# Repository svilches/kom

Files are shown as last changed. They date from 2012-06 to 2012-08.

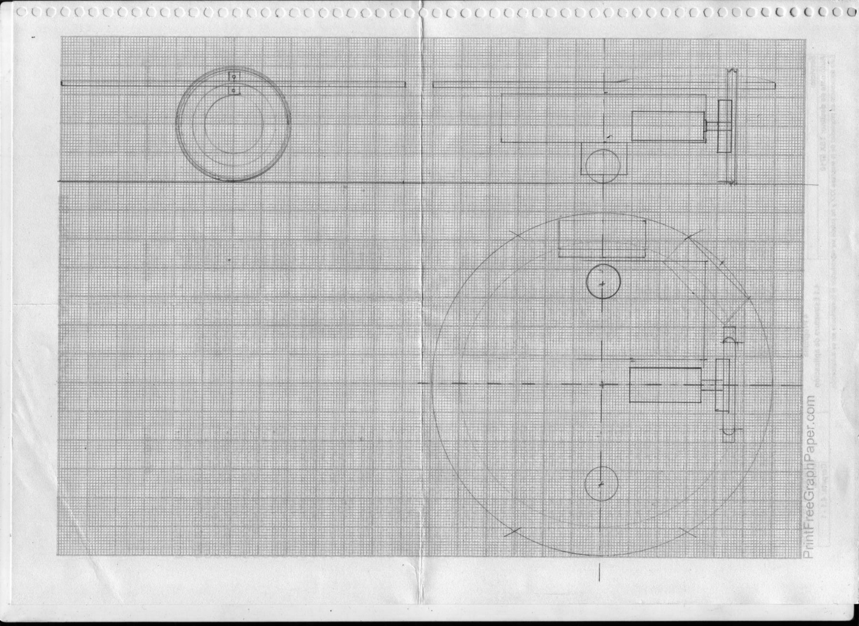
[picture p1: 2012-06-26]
hw/doc/mechs/chassisReqs.jpg

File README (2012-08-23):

CONTENT
kom project source files for both hardware and software
Will include all the source files and documentation for both hardware and software.

GIT RESOURCES
 - Starting point:
	http://www.gitguys.com/topics/skip-the-intro/
 - GIT Book:
	http://git-scm.com/book/ch1-3.html
 - gitg, a graphical tool to see what you are doing to the repository
	sudo apt-get install gitg

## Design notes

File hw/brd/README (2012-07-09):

I'm using the latest kicad (testing) from Adam Wolf's ppa. To use it in Ubuntu:
sudo add-apt-repository ppa:adamwolf/kicad-testing-daily

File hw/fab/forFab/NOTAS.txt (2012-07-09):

Proyecto KOM - Robot KOMbot
== Sergio Vilches ==
- PCB circular, diámetro 130mm
- Hay 2 rendijas en el interior de la PCB a mecanizar. Las ruedas del robot atraviesan la PCB!!! Aparecen en el archivo kom-PCB_Edges.gbr

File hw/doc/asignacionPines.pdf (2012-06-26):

# Asignación de Pines

Arduino Pin | AVR pin | Notas | Uso
0 | PD0 | RX | Conectado al TX del FTDI, Bluetooth o XBee
1 | PD1 | TX | Conectado al RX del FTDI, Bluetooth o XBee
2 | PD2 | INT0 | PUSH, SERVO
3 | PD3 | INT1, PWM | SpeedL
4 | PD4 | | DIR_L
5 | PD5 | PWM*¹ | PWROUT, IRLEDs
6 | PD6 | PWM*² | PWROUT, SERVO
7 | PD7 | | DIR_R
8 | PB0 | | A
9 | PB1 | PWM³ | B
10 | PB2 | PWM⁴ | C
11 | PB3 | PWM,MOSI | SpeedR
12 | PB4 | MISO | D
13 | PB5 | SCK | ServoScanner
A0 | PC0 | | MUX

1
The PWM outputs generated on pins 5 and 6 will have higher-than-expected duty cycles. This is because of interactions with the millis() and delay() functions, which share the same internal timer used to generate those PWM outputs. This will be noticed mostly on low duty-cycle settings (e.g 0 - 10) and may result in a value of 0 not fully turning off the output on pins 5 and 6.
2
(Same)

3
Disabled by Servo.h

4
Disabled by Servo.h

A1 | PC1 | | SERVO, R
A2 | PC2 | | SERVO, G
A3 | PC3 | | SERVO, B
A4 | PC4 | I2C_SDA
A5 | PC5 | I2C_SCL
MUX Pin | Uso

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
8 | encLA
9 | encLB
10 | encRA
11 | encRB
12 | US0
13 | US1
14 | IR0
15 | 0.4*Vin

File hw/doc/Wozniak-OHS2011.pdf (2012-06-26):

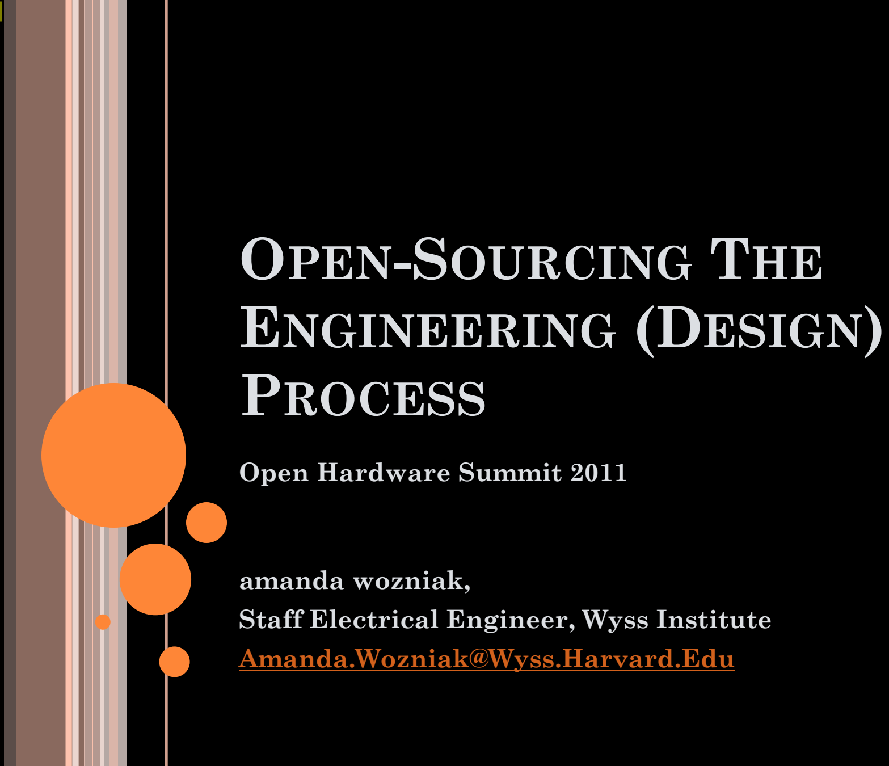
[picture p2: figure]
OPEN-SOURCING THE ENGINEERING (DESIGN) PROCESS; amanda wozniak, Staff Electrical Engineer, Wyss Institute Amanda.Wozniak@Wyss.Harvard.Edu; Open Hardware Summit 2011

FIRST OFF, WHAT IS THE ENGINEERING PROCESS?

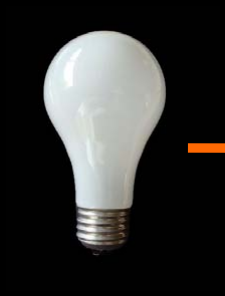
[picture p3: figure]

great idea
for a project

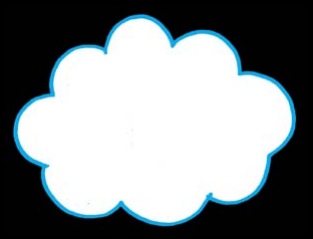
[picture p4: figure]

a miracle
occurs!

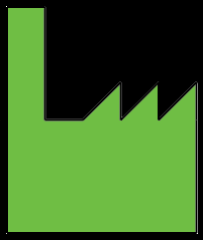
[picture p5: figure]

fabrication
and
assembly

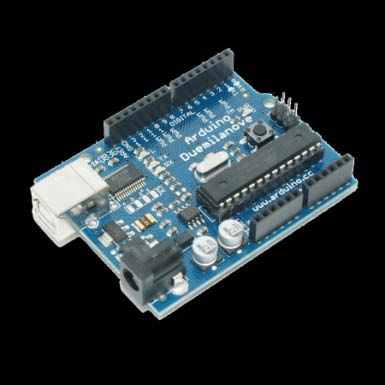
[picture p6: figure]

hardware

IT’S ALL OF THIS.

THE IDEA OF A DOCUMENTING A PROCESS IS DEAD SIMPLE. ACTUALLY DOCUMENTING A SPECIFIC PROCESS IS INCREDIBLY HARD.

system
description

SCH

BOM

pcb
layout
design
rules

user
guide

source
code manufacturing
rules | typical application note

block
diagram

GERBER

description
of trade-offs &
limitations

bug list

safety & reliability
concerns potential
hazards

design for
manufacturing

test plan

SCHEMATICS, GERBERS AND BOMS ARE A
SUFFICIENT FOR MANUFACTURING. WHY BOTHER WITH A PROCESS? SHOULDN’T WHAT WE MAKE BE ENOUGH?

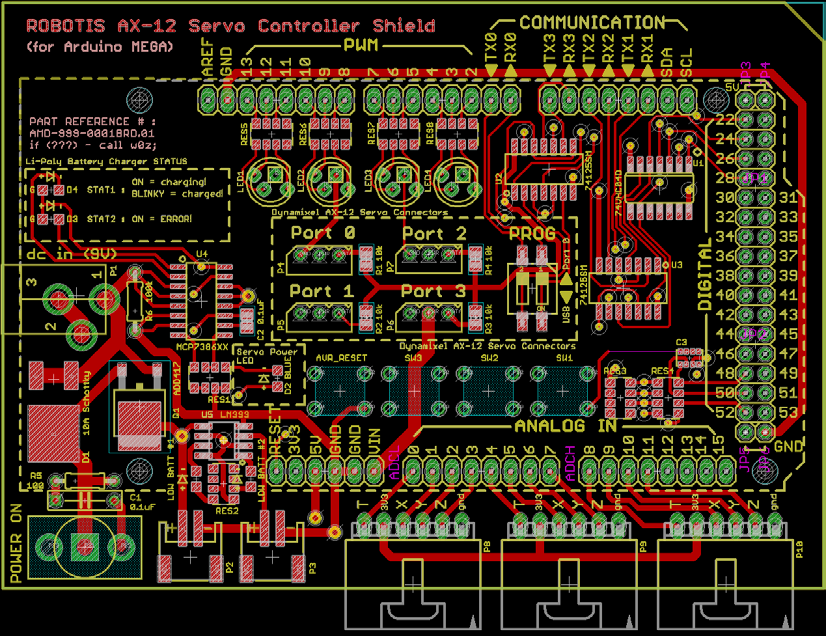
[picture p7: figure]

WHAT’S SO OPEN ABOUT YOUR
HARDWARE IF I HAVE TO REVERSE-ENGINEER IT TO CONTRIBUTE?

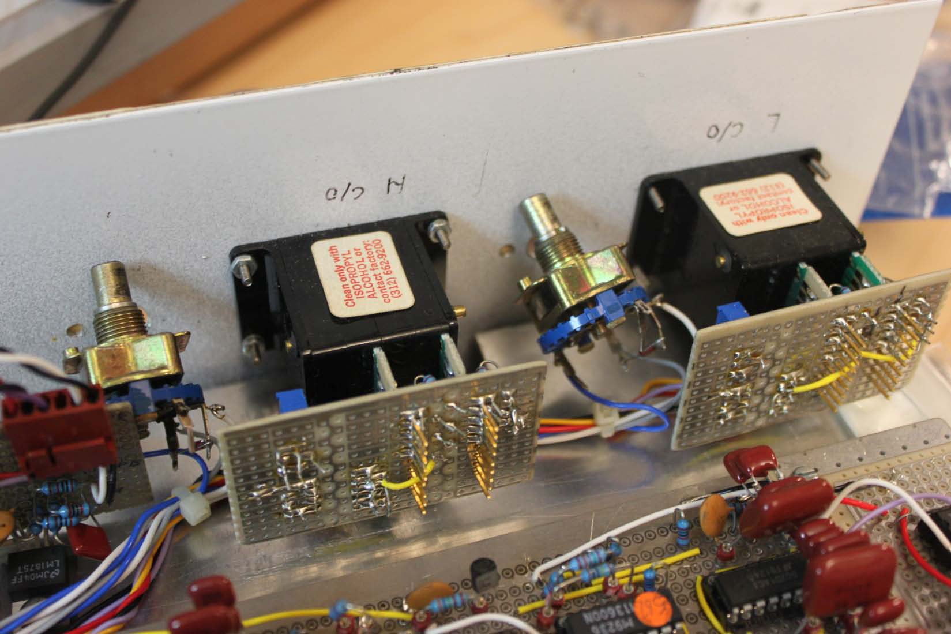
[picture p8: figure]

INDUSTRY IS SO SUCCESSFUL, BECAUSE UNDERNEATH ALL THE NDAS, EVERYTHING IS EXPOSED.

IN ADDITION TO BEING OPEN, FORMAL DESIGN PROCESSES OFTEN SAVE YOUR BACON

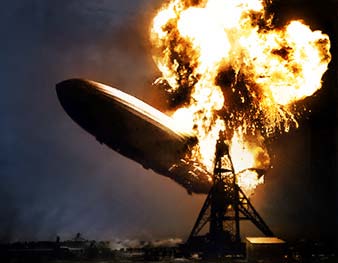
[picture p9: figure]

SURE, SOCIETY COULD COLLAPSE FROM INSUFFICIENT DOCUMENTATION.

DON’T LET THAT INTIMIDATE YOU.

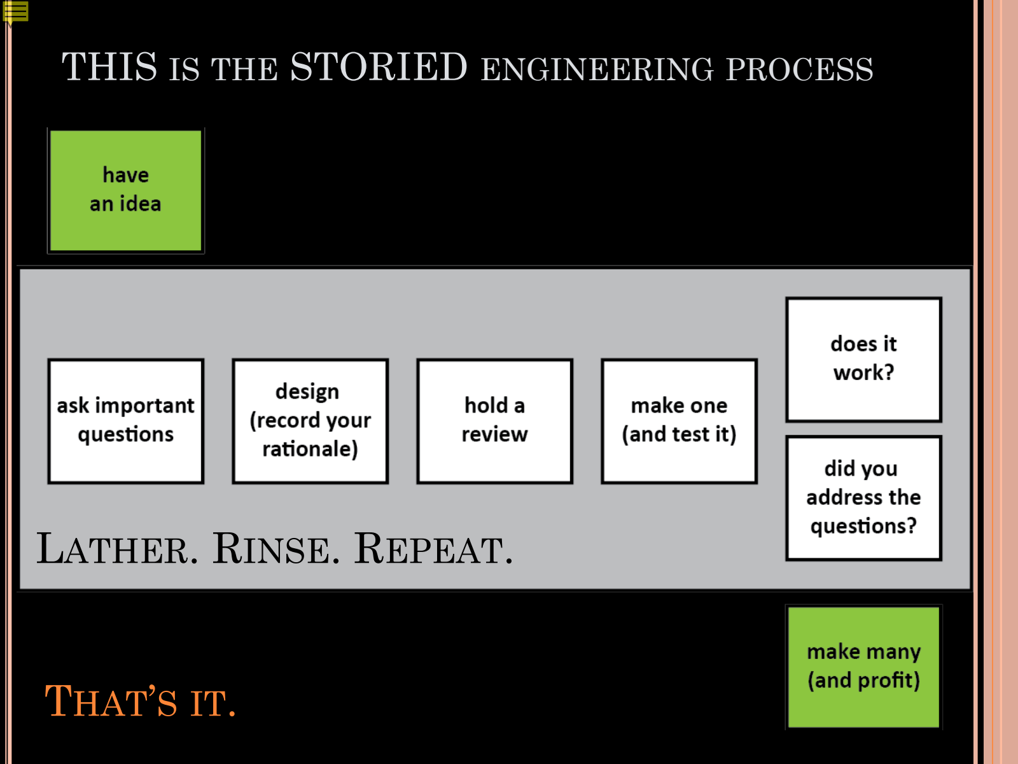
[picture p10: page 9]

THIS IS THE STORIED ENGINEERING PROCESS

LATHER. RINSE. REPEAT.

THAT’S IT.

PROJECT GOAL: AUTONOMOUS ROBOT

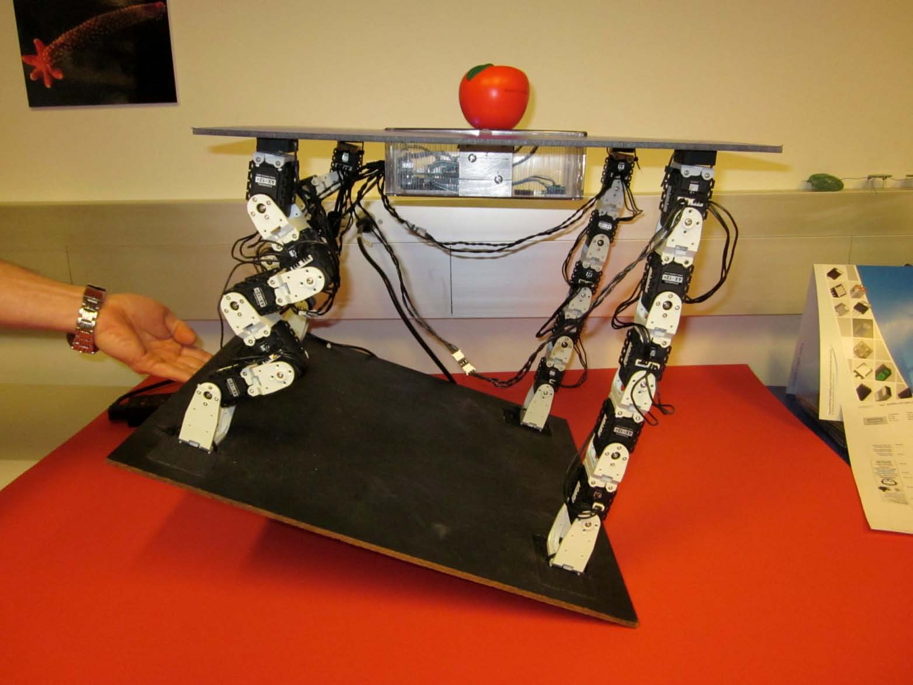
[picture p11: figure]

FIRST, I ASKED SOME QUESTIONS…

- Why are we making this?
- Who is this for?
- How will this be used?
- What features does it need to have (now)?
- What features does it need to have (later)?
- What are the legacy requirements?
- Who’s going to build this?
- How many do we want to make?
- What is the budget?
- What is the timeline?

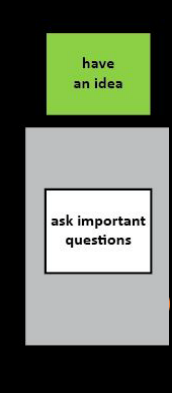
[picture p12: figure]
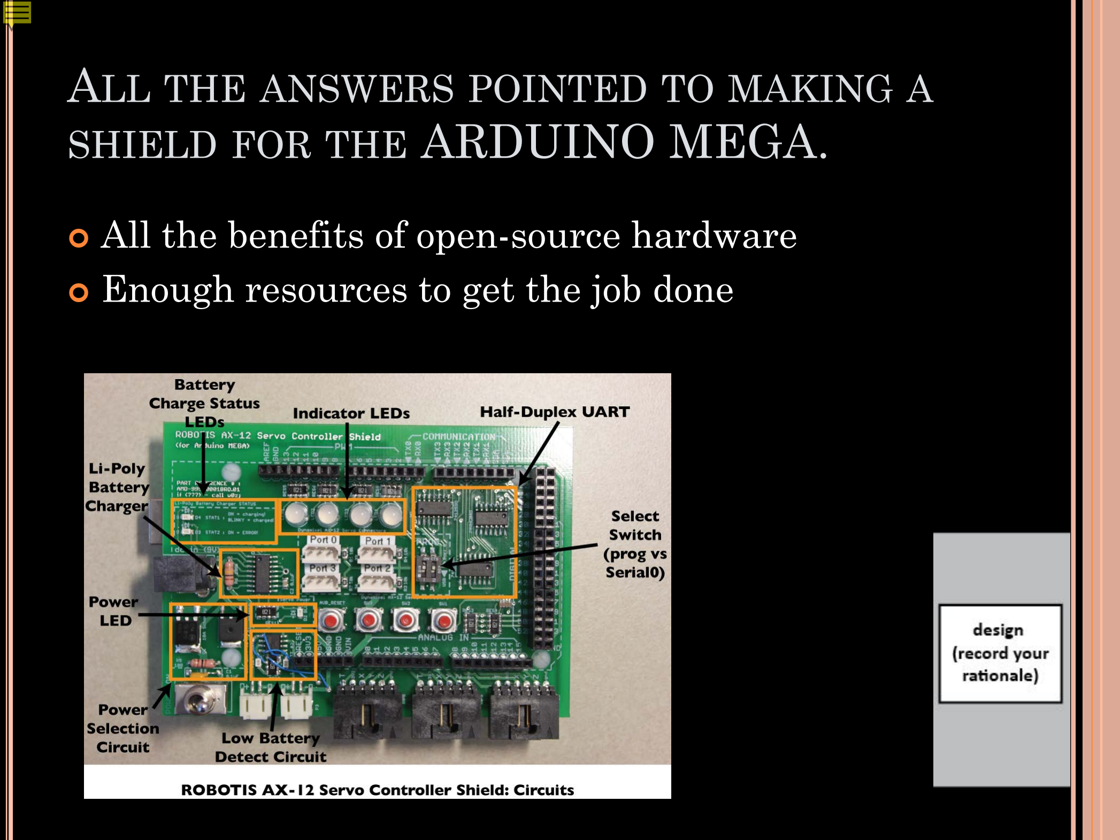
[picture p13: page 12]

ALL THE ANSWERS POINTED TO MAKING A SHIELD FOR THE ARDUINO MEGA.

- All the benefits of open-source hardware
- Enough resources to get the job done

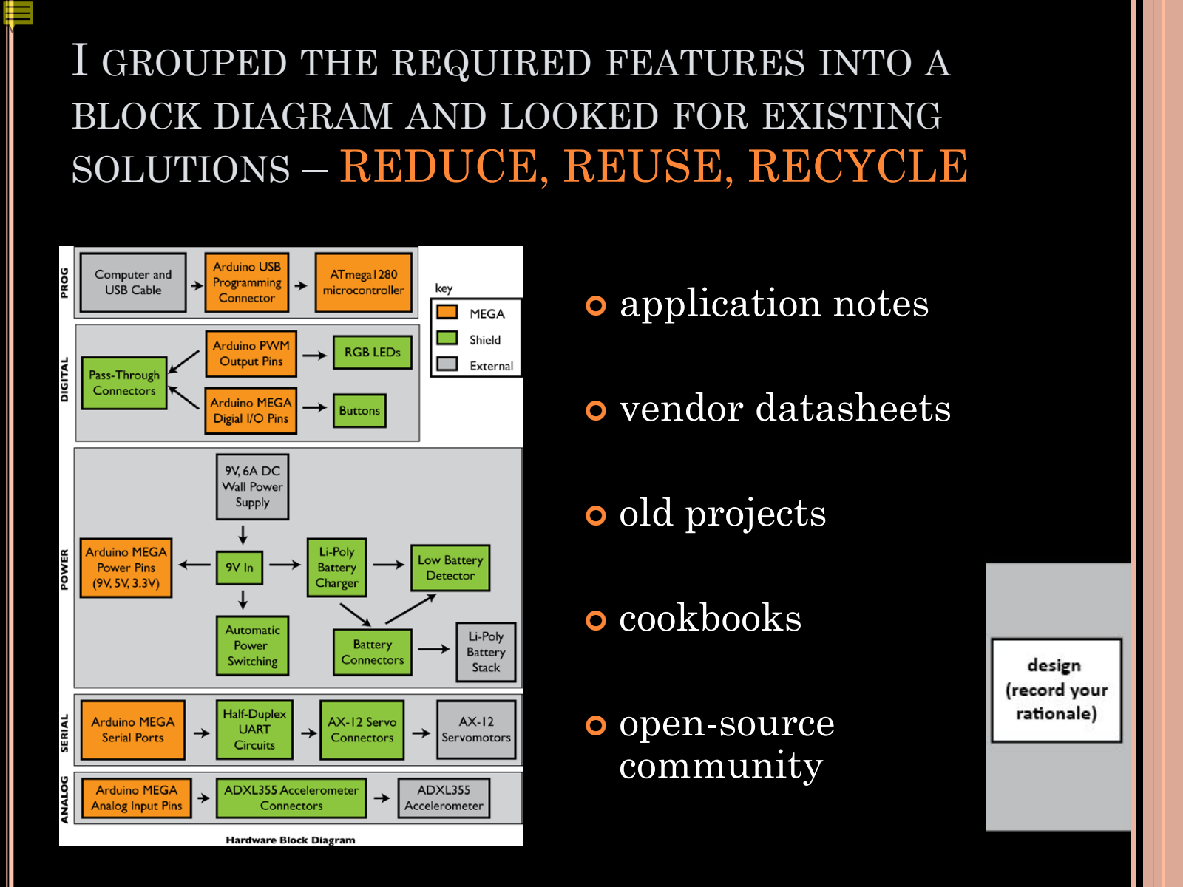
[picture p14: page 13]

I GROUPED THE REQUIRED FEATURES INTO A BLOCK DIAGRAM AND LOOKED FOR EXISTING
SOLUTIONS – REDUCE, REUSE, RECYCLE
- application notes
- vendor datasheets
- old projects
- cookbooks
- open-source
community

HARDWARE DESIGN WORK-FLOW

- Parts Selection and Schematic Capture
- Schematic Review – REVISIT QUESTIONS
- Layout Floor-planning (mechanical)
- PCB Layout
- Schematic + Layout Review – REVISIT QUESTIONS
- Pre-Tapeout Verification
- Manufacturing Tape-out
- Test and Characterization
- Iterate (if necessary)
- Document
- Release

### BEST PRACTICES: SCH/BOM

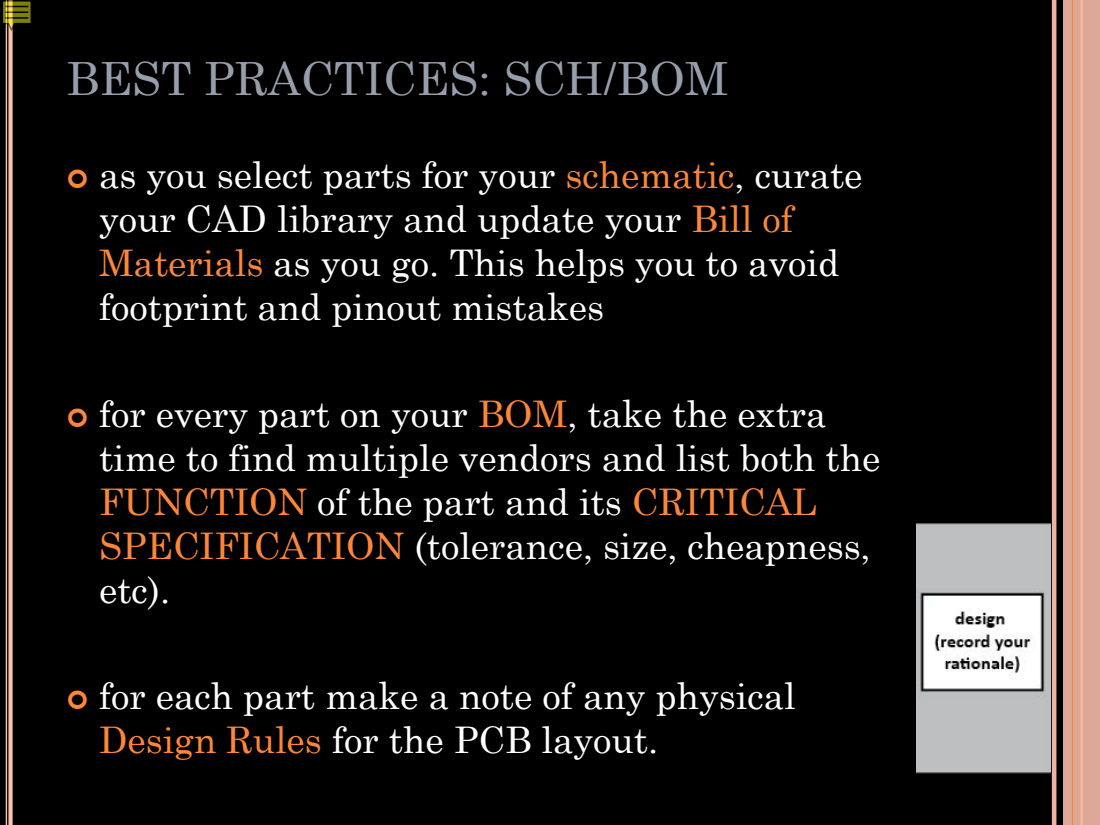
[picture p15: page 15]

as you select parts for your schematic, curate
your CAD library and update your Bill of
Materials as you go. This helps you to avoid
footprint and pinout mistakes

for every part on your BOM, take the extra
time to find multiple vendors and list both the
FUNCTION of the part and its CRITICAL
SPECIFICATION (tolerance, size, cheapness,
etc).

for each part make a note of any physical
Design Rules for the PCB layout.

### BEST PRACTICES: PCB/PROTOTYPE

- Take your Design Rules and follow them to the best of your ability.
- Verify against Schematic.
- Review with others. REVISIT QUESTIONS.

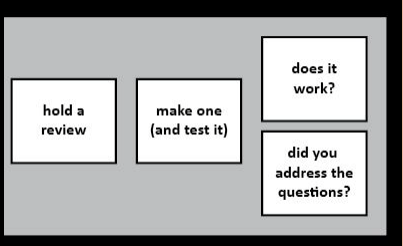
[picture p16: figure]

- Built. Test.
- Iterate until satisfied.

PRE-TAPEOUT CHECKLIST

- Have you fixed all DRC/ERC errors?
- All part footprints on PCB match BOM?
- All part pin-outs on schematic match data sheet?
- Does your schematic match your working proto?
- Did you verify the critical spec for each part?
- Did you find the right vendor part number for each part?
- Is your part in stock? (BUY IT NOW)
- All Pin-1 designators correct?
- All RefDes labels correct?

FABRICATION PACKAGE CHECKLIST

- GERBERS
- NC Drill File
- Assembly Drawing
- Pick & Place Coordinates
- BOM
- Part ID
- Reference Designator(s)
- Part Type
- Package Footprint
- Value/Description/Critical Spec
- Manufacturer’s Part Number
- Vendor’s Part Number

SO, NOW YOUR DESIGN DOCUMENTATION IS JUST COMPILING WHAT YOU ALREADY KNOW
- Project Introduction (Goals, Overview)
- System Block Diagram
- Discussion of Essential Features/Trade-offs
- Block-by-Block Breakdown
- Function
- Schematic block
- Layout block
- Parts selection (and critical specs)
- Performance metrics (if applicable)
- Software/Firmware Summary
- Typical Application
- User’s Quick-Start Guide
- Errata

WHY BOTHER WITH ALL OF THAT PROCESS AND DETAIL FOR A DEMO?

WHEN YOU FOLLOW A PROCESS, YOU GAIN EFFICIENCY. WHEN WE NEEDED TO PROTOTYPE A DIAGNOSTIC MICROSCOPE, I HAD ALL THE PARTS.

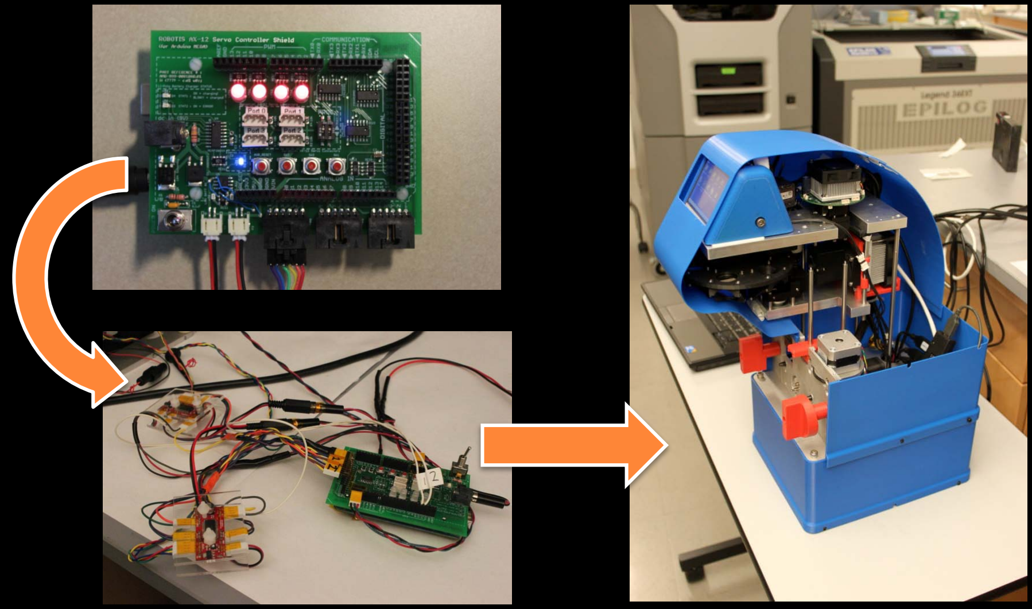
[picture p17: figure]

HOBBY PROJECT OR INDUSTRY PRODUCT, THE GIST OF THE PROCESS REMAINS THE SAME – ONLY THE DETAILS CHANGE

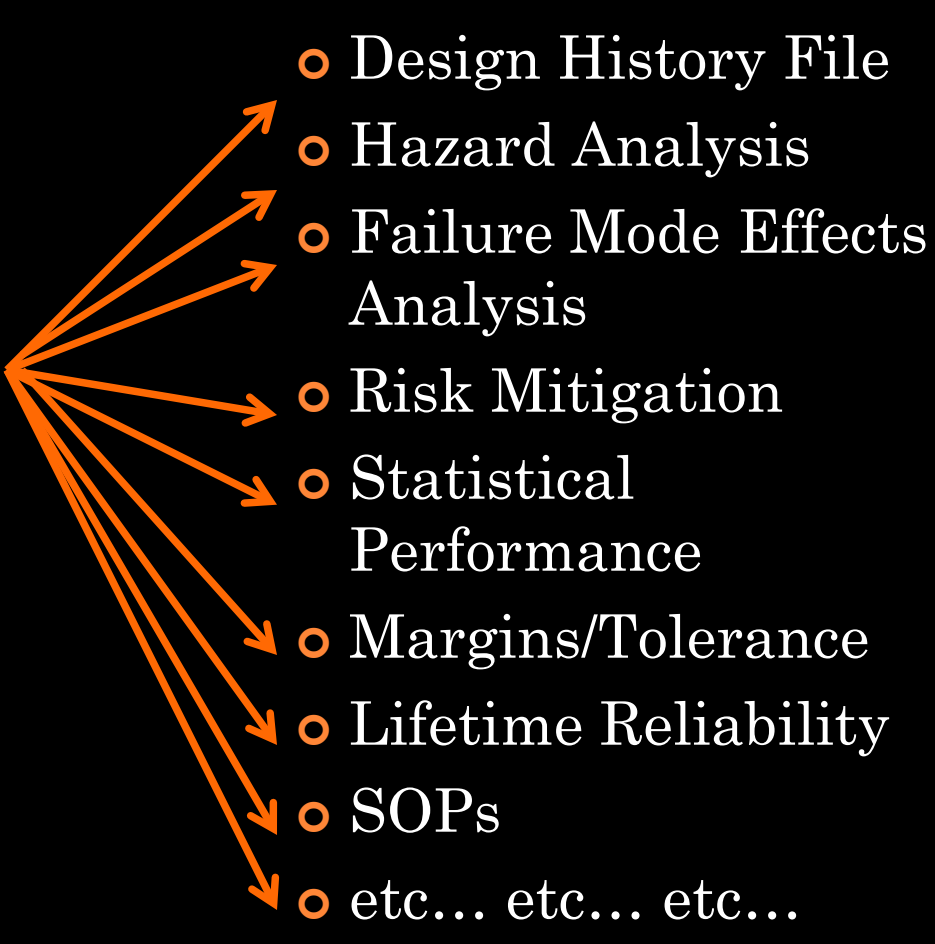
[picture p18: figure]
Design History File Hazard Analysis Failure Mode Effects Analysis Risk Mitigation Statistical Performance Margins/Tolerance Lifetime Reliability SOPs etc… etc… etc…

- README.txt
- Schematic
- Gerber
- BOM

PROCESS TRANSPARENCY ALLOWS YOU TO

### CONQUER:

- ANALYST BIAS – “The previous guy knew what he was doing better than I do.”
- HUBRIS – “I know best, that other guy is an idiot.”
- CARGO CULT THINKING – “Engineering must be magic. If we copy it and it looks the same, it’s got to work, right?”

THE MORE WE SHARE, THE MORE OTHERS CAN QUESTION OUR DESIGN… THE FASTER WE CAN LEARN FROM OUR COLLECTIVE MISTAKES AND THE SOONER WE CAN CELEBRATE OUR COLLECTIVE SUCCESSES.

QUESTIONS? COMMENTS? DROP A LINE.

- professional contact:
amanda.wozniak@wyss.harvard.edu
- personal contact: woz@mit.edu

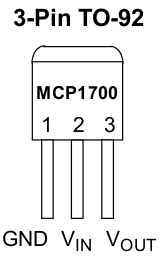
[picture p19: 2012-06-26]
hw/doc/datasheets/MCP1700_pinout.png

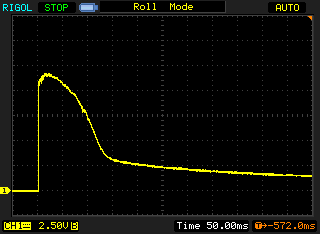
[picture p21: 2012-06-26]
hw/doc/oscope/LiPoFuseShortCircuit.bmp

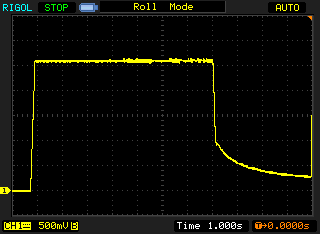
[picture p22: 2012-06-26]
hw/doc/oscope/LiPoFuse2.5A.bmp

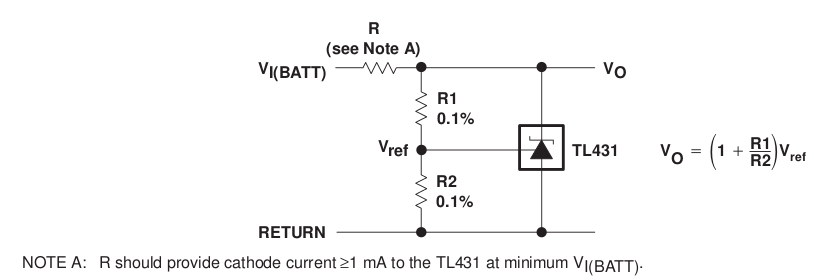
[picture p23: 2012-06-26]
hw/doc/datasheets/vRef_sch.png

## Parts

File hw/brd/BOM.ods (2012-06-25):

ref | value | to buy?
AREF1 | CONN_1
BT1 | BLUETOOTHMOD_DX
BypC1 | IR
BypC2 | H
BypC3 | Servo
BypC4 | US
BypC5 | Mux
C1 | 100nF
C2 | 100uF(min)
C3 | 22pF
C4 | 0.1u
C5 | 22pF
C6 | 100uF(min)
CP1 | PWR1
CP2 | PWR2
CP3 | LMotor
CP4 | RMotor
D1 | DIODE
D2 | RSSI
D3 | UVLO
D4 | IR_LED
D5 | IR_LED
D6 | IR_LED
D7 | IR_LED
D8 | IR_LD271
D9 | IR_LD271
D10 | IR_LD271
F1 | FUSE
H1 | ICSP
I2C | JP_4
IC1 | ATMEGA328-P
IC2 | 4067D | Y | http://es.farnell.com/texas-instruments/cd74hc4067e/logic-mux-demux-analog-hs-24dip/dp/1740160
IC3 | L293D | Y | http://es.farnell.com/texas-instruments/l293dne/ic-driver-peripheral-dual-36v/dp/1470423
J?1 | EXT | Y | http://es.farnell.com/lumberg/neb-21-r/socket-low-voltage-2-1mm-4a/dp/1217037 http://es.farnell.com/multicomp/mp-121m-grey/plug-low-voltage/dp/1737253
JP1 | ServoScanner
LED1 | LED_ARBG
LED2 | LED_ARBG
LED3 | LED_ARBG
M1 | XBEE
P1 | Batt | Y | Jon – Alberto
P2 | Serial
P4 | GPIO_4PIN
P5 | GPIO_4PIN
P6 | GPIO_4PIN
P7 | GPIO_4PIN
P8 | GPIO_4PIN
P9 | GPIO_4PIN
P10 | IR_Scanner
P11 | GPIO_4PIN
P12 | GPIO_4PIN
P13 | GPIO_4PIN
P14 | GPIO_4PIN
P15 | GPIO_4PIN
P16 | GPIO_4PIN
P17 | GPIO_4PIN
P18 | GPIO_4PIN
Q1 | PT480F
Q2 | PT480F
Q3 | PT480F
Q4 | PT480F
R1 | 1.5K
R2 | 1.5K
R3 | 10K
R4 | 220
R5 | 15K
R6 | 10K
R7 | 1k
R8 | 348
R9 | 10K
R10 | 220
R11 | 2.2K
R12 | 220
R13 | 2.2K
R14 | 220
R15 | 500
R16 | 2.2K
R17 | 220
R18 | 2.2K
R19 | 180
R20 | 180
R21 | 120
R22 | 15
SW1 | SW_RESET
SW2 | PwrSelect | Y | http://es.farnell.com/eao/09-03290-01/slide-switch-spdt-vert/dp/674345
SW3 | PWR_Control
SW4 | TEST
U1 | LM7833
U2 | 74LS125
U3 | TC54
U4 | PTH08000WAZT
U5 | ULN2003A | Y | http://es.farnell.com/texas-instruments/uln2003ane4/darlington-array-7npn-2003-dip16/dp/1210973
US1 | US_L
US2 | US_R
X1 | 16MHz

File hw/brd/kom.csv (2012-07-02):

ref | value
BC1 | BC547
BT1 | BLUETOOTHMOD_DX
C1 | 100nF
C2 | 22pF
C3 | 0.1u
C4 | 22pF
C5 | 100n MUX
C6 | 100n AVR
C7 | 100n AVCC
C8 | 8.2pF Radio
C9 | 100nF MotorL
C10 | 100nF MotorR
CAP1 | 100uF InCap
CAP2 | 10uF IR
CAP3 | 100uF HBridge
CAP4 | 10uF US
CAP5 | 1uF Radio
CP1 | LMotor
CP2 | RMotor
D1 | RSSI
D2 | UVLO
D3 | ON
D4 | IR_LED
D5 | IR_LED
D6 | IR_LED
D7 | IR_LED
D8 | IR_LD271
D9 | IR_LD271
D10 | IR_LD271
F1 | 1.1A Fuse
I1 | I2C
I2 | I2C
IC1 | ATMEGA328-P
IC2 | 4067D
IC3 | L293D
InvPolDiode1 | 200mA IPP
J1 | LiPo
J2 | EXT
JP1 | ServoScanner
LED1 | LED_RCGB
LED2 | LED_RCGB
LED3 | LED_RCGB
M1 | XBEE
P1 | Serial
P2 | ARef
P3 | D2
P4 | D5
P5 | D6
P6 | A1
P7 | A2
P8 | A3
P9 | IR_Scanner
P10 | X0
P11 | X1
P12 | X2
P13 | X3
P14 | X4
P15 | X5
P16 | X6
P17 | X7
Q1 | PT480F
Q2 | PT480F
Q3 | PT480F
Q4 | PT480F
R1 | 1.5K
R2 | 1.5K
R3 | 10K
R4 | 15K
R5 | 10K
R6 | 220
R7 | 1k
R8 | 348
R9 | 10K
R10 | 330
R11 | 2.2K
R12 | 500
R13 | 2.2K
R14 | 2.2K
R15 | 2.2K
R16 | 180
R17 | 180
R18 | 120
R19 | 20
SW1 | SW_RESET
SW2 | PwrOn
SW3 | PWR_Control
SW4 | TEST
U1 | 10uH
U2 | MCP1700-3302E
U3 | 74LS125
U4 | TC54
U5 | PTH08000WAZT
US1 | US_L
US2 | US_R
X1 | 16MHz

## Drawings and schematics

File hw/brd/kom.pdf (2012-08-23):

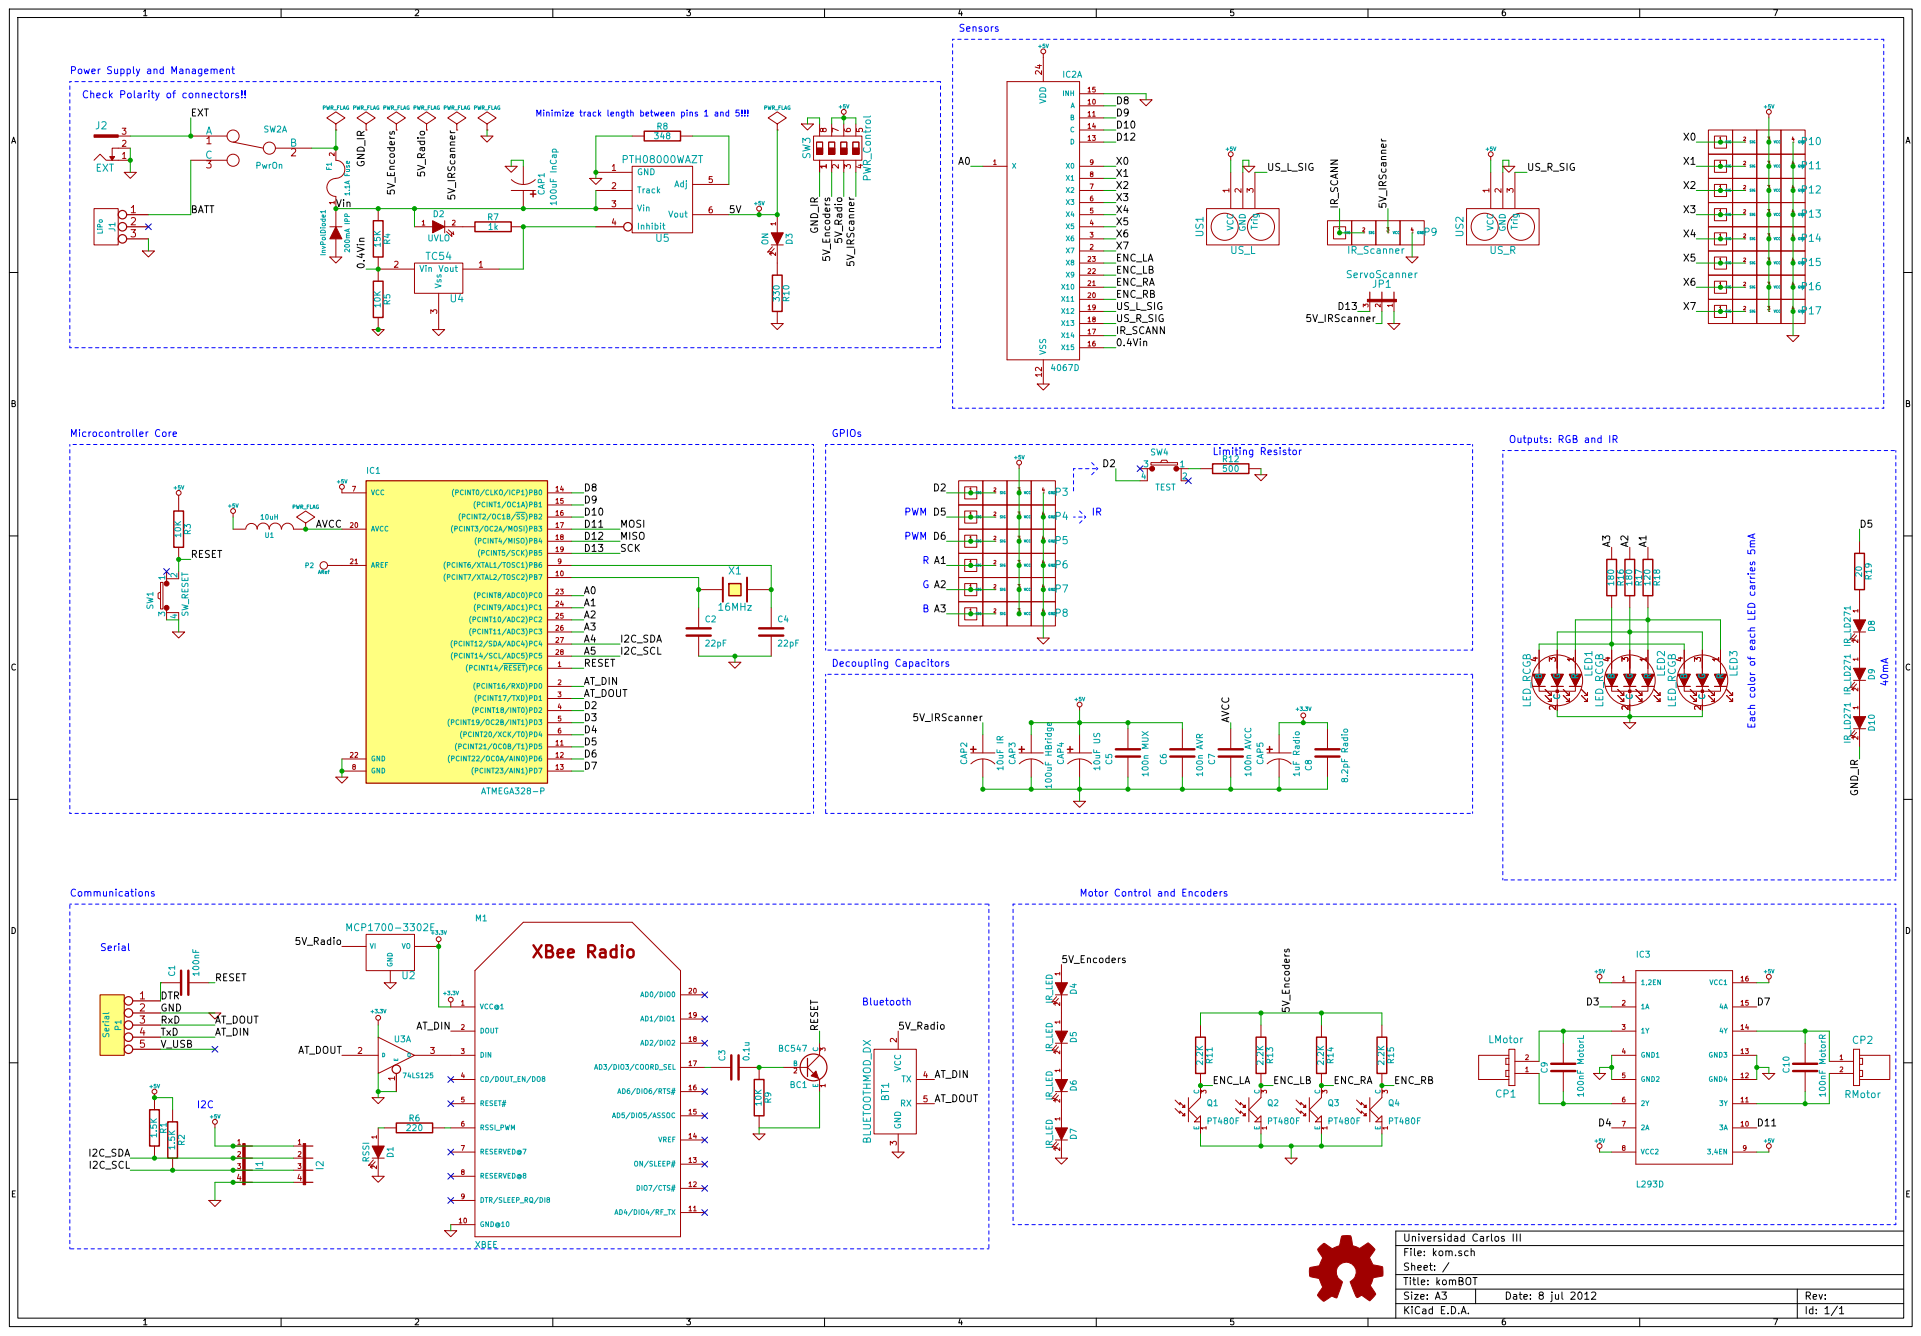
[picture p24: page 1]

1 2 F1 1.1A Fuse Check Polarity of connectors!! A

SIG 2 | VCC 3

SIG 1 SIG 2 | VCC 3

SIG 2

SIG 1 SIG 2 | VCC 3 | GND 4 | P8 D2 D5 D6A1A2A3

SIG 1 SIG 2

File: kom.sch Sheet: / Universidad Carlos III

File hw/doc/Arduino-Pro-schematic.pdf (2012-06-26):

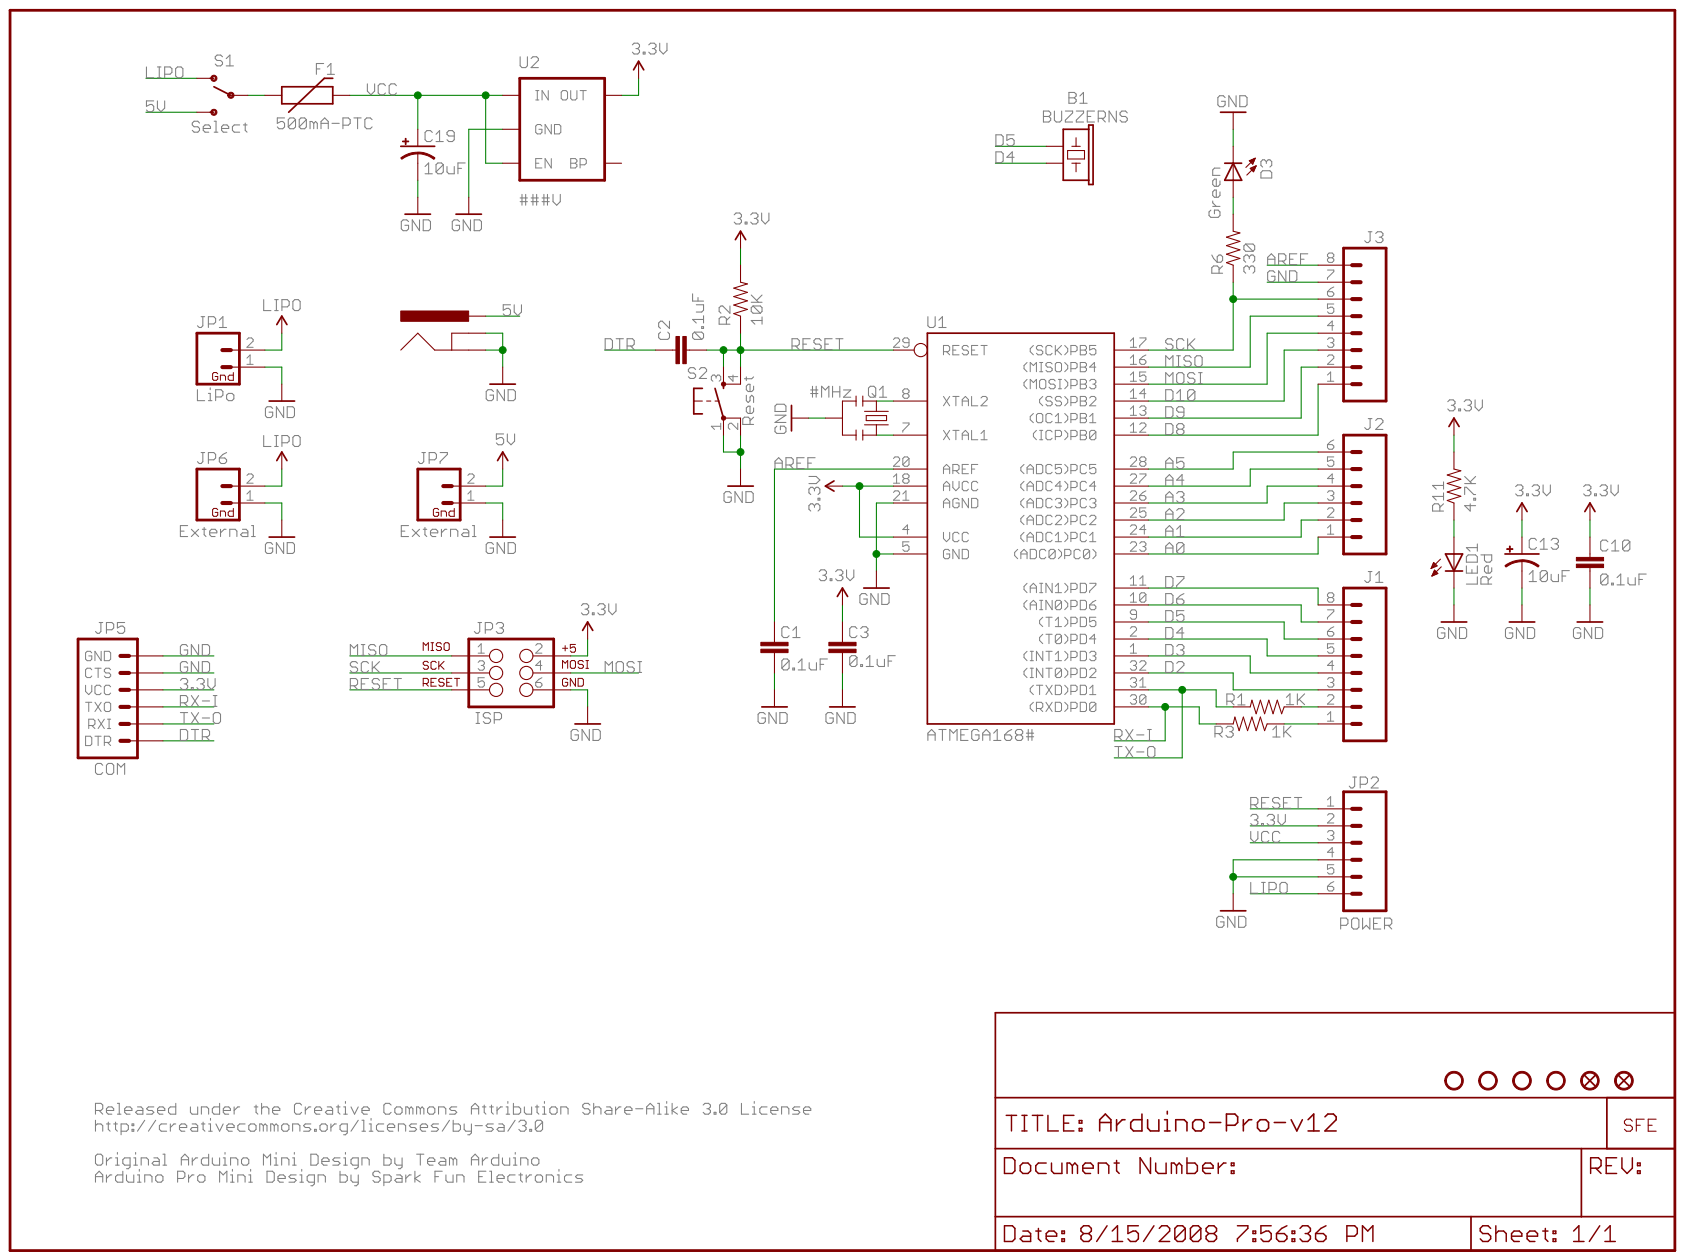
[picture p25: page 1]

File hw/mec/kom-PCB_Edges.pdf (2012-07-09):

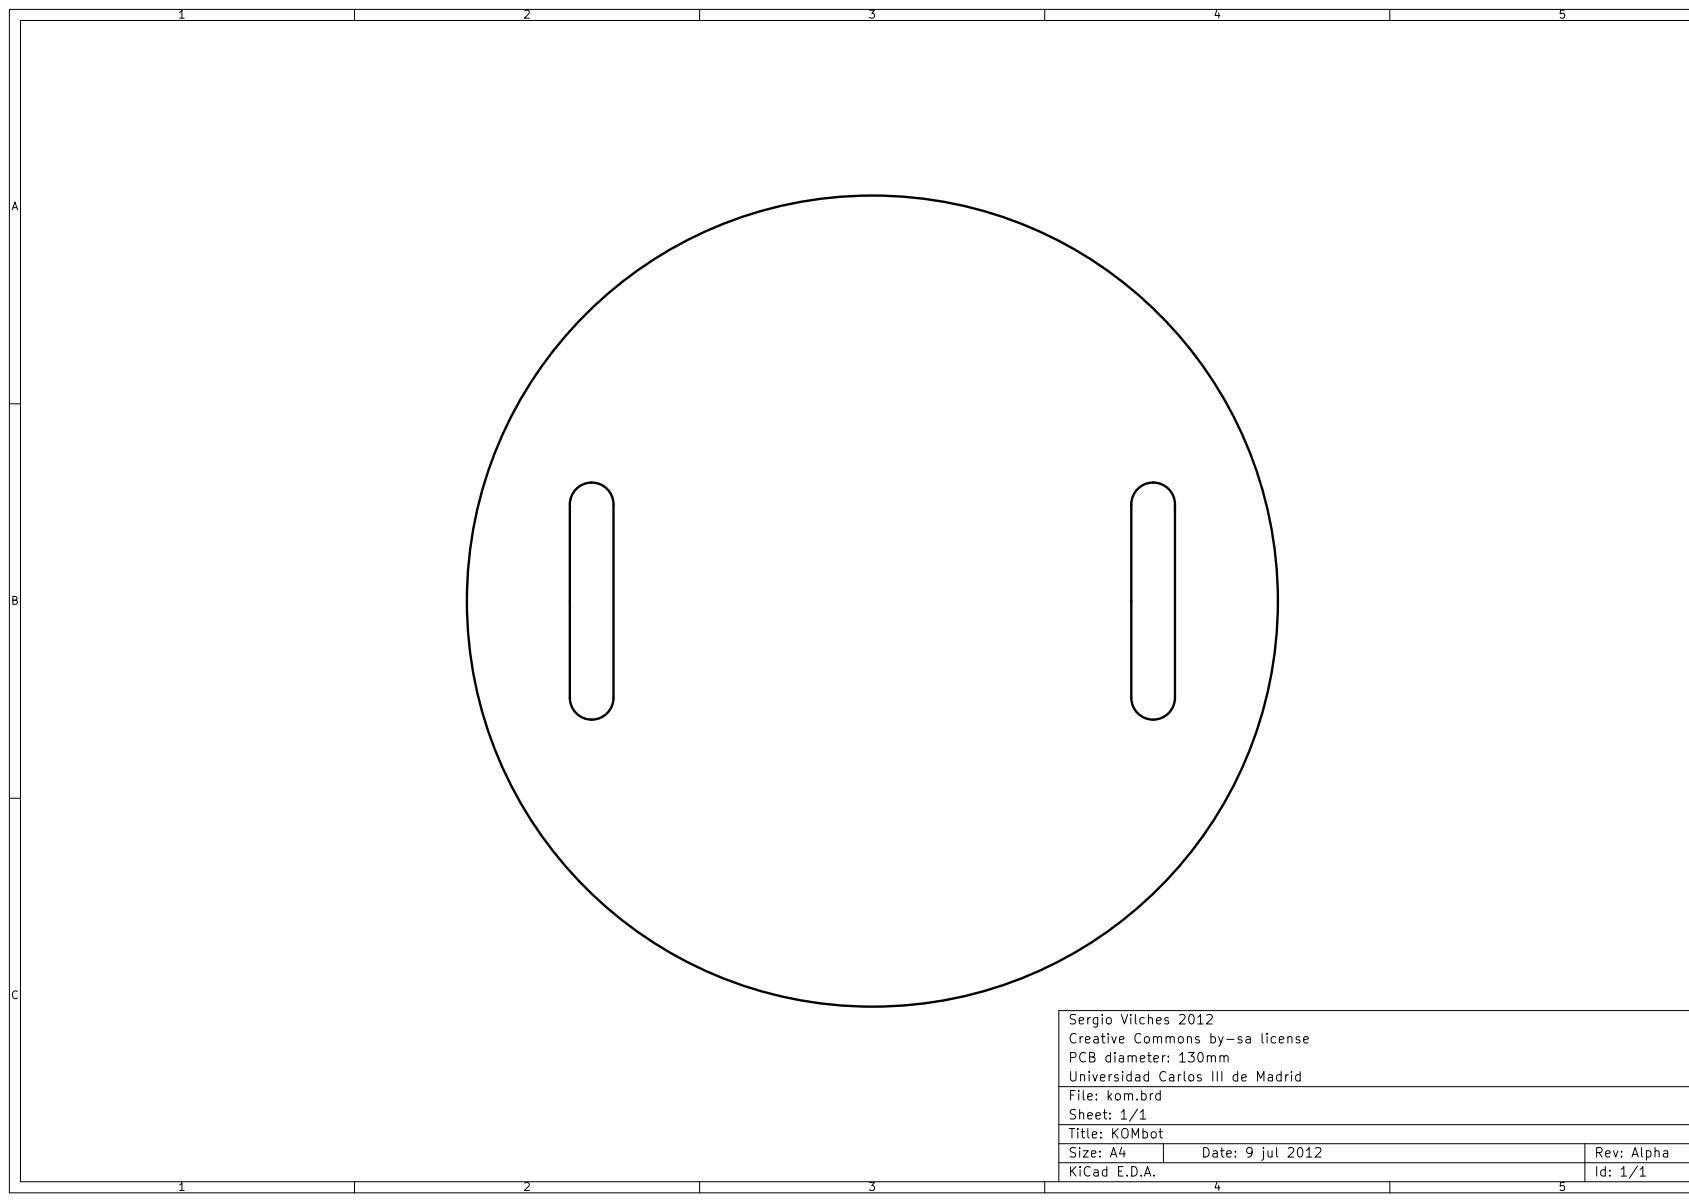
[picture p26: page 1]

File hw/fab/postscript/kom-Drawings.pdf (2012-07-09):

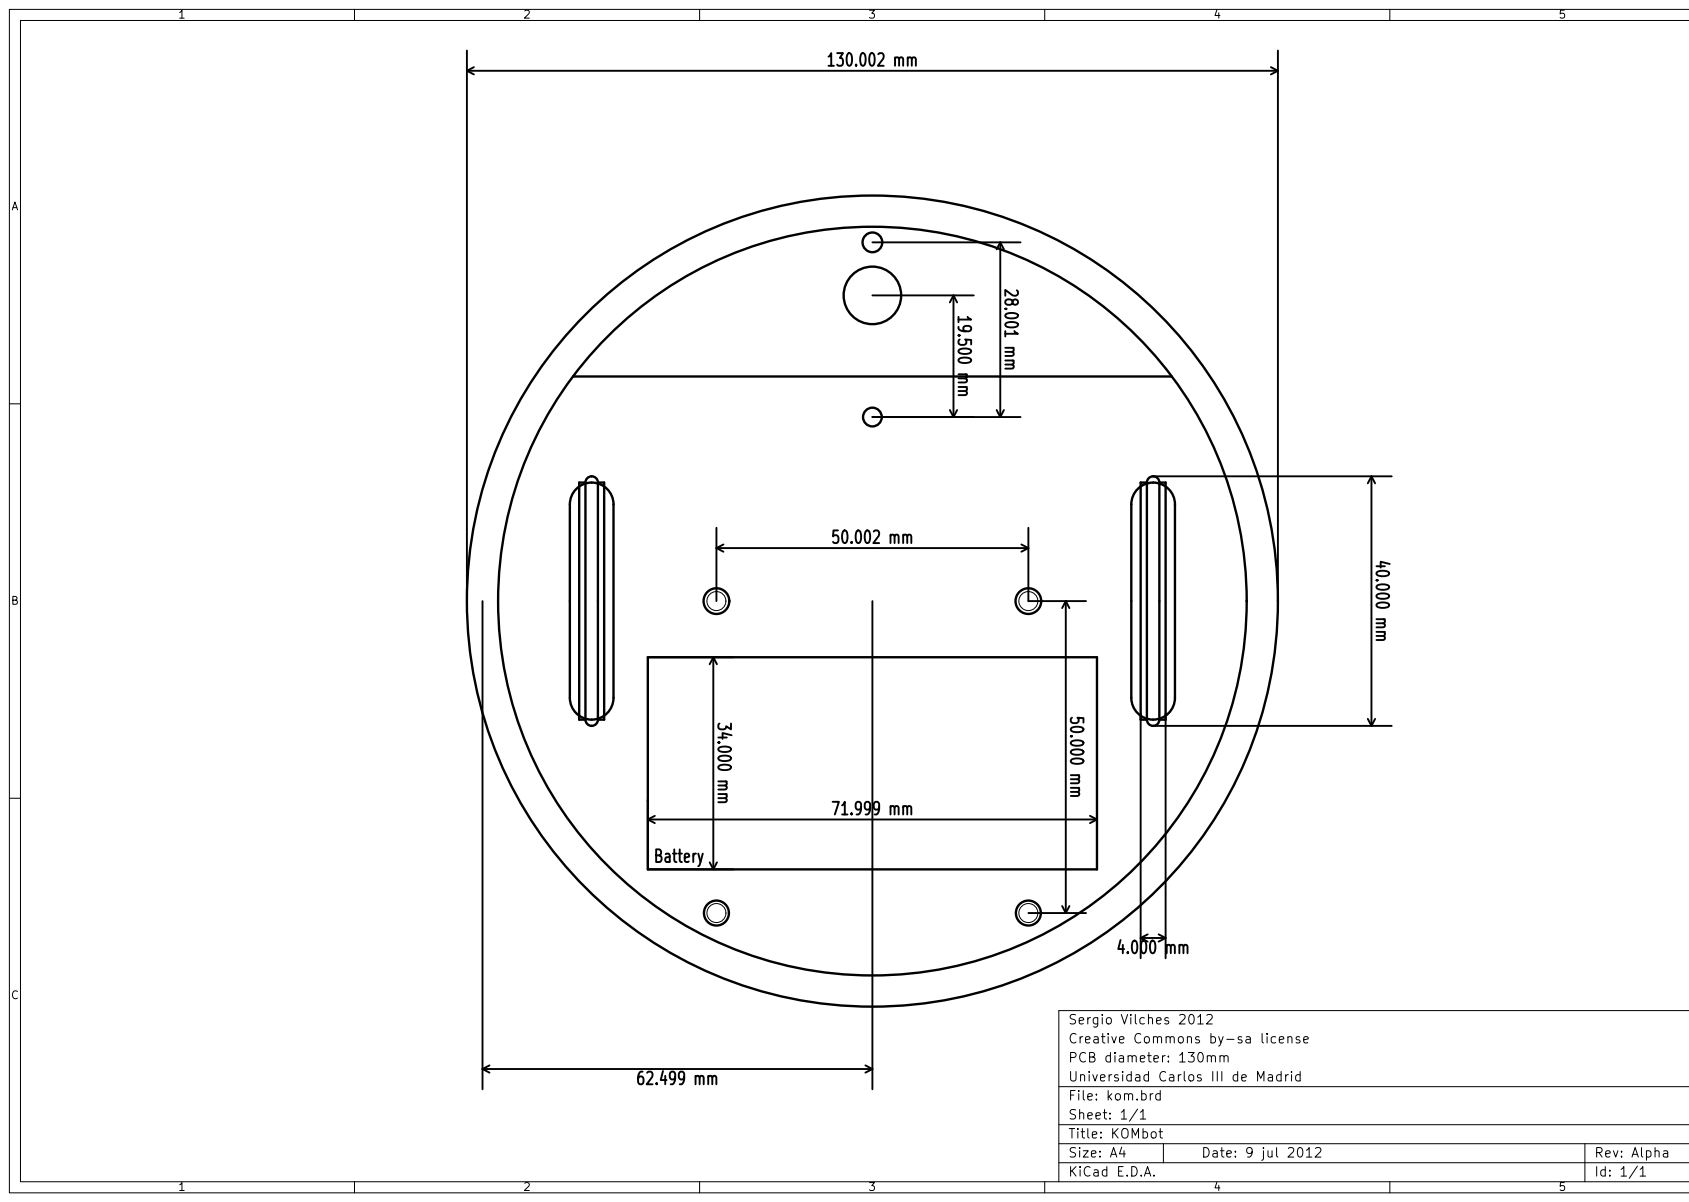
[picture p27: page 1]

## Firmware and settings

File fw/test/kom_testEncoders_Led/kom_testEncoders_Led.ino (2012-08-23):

#include <Servo.h> 

/* NOTES:
 - Switching analog pins in close temporal proximity to making A/D reading can introduce jitter...
 - 
 */

///////////////////
// Hardware defines
///////////////////

// Multiplexer:
const int MUX_X_PIN = A0;

const int MUX_A_PIN = 8;  // LSB
const int MUX_B_PIN = 9;
const int MUX_C_PIN = 10;
const int MUX_D_PIN = 12;  // MSB  



// H-Bridge:
const int L_DIR_PIN = 4;
const int L_VEL_PIN = 3;
const int R_DIR_PIN = 7;
const int R_VEL_PIN = 11;

// RGB LEDs:
const int LED_R_PIN = A1;
const int LED_G_PIN = A2;
const int LED_B_PIN = A3;

// IR LEDs:
const int LED_IR_PIN = 5;

// Test Pushbutton:
const int PUSH_PIN = 2;

// Servo Scanner:
const int SERVO_PIN = 13;

/////////////////////
// Global Variables
/////////////////////
Servo irServo;

//////////
// Setup
//////////
void setup() {                
  pinMode(MUX_A_PIN, OUTPUT);
  pinMode(MUX_B_PIN, OUTPUT);
  pinMode(MUX_C_PIN, OUTPUT);
  pinMode(MUX_D_PIN, OUTPUT);

  pinMode(L_DIR_PIN, OUTPUT);
  pinMode(L_VEL_PIN, OUTPUT);
  pinMode(R_DIR_PIN, OUTPUT);
  pinMode(R_VEL_PIN, OUTPUT);

  pinMode(LED_R_PIN, OUTPUT);
  pinMode(LED_G_PIN, OUTPUT);
  pinMode(LED_B_PIN, OUTPUT);
  pinMode(LED_IR_PIN, OUTPUT);

  pinMode(SERVO_PIN, OUTPUT);

  pinMode(PUSH_PIN, INPUT);
  digitalWrite(PUSH_PIN, HIGH);

  Serial.begin(57600);

  irServo.attach(SERVO_PIN);
}


void setMotorVal(int lv, int rv){
  // Left motor
  if (lv>255) lv = 255;
  if (lv<-255) lv = -255;

  if (lv>=0){  // CW
    digitalWrite(L_DIR_PIN,LOW);
    analogWrite(L_VEL_PIN,lv);
  }

  if (lv<0){  // CCW
    digitalWrite(L_DIR_PIN,HIGH);
    analogWrite(L_VEL_PIN,255 + lv);
  }

  rv=-rv;
  // Right motor
  if (rv>255) rv = 255;
  if (rv<-255) rv = -255;

  if (rv>=0){  // CW
    digitalWrite(R_DIR_PIN,LOW);
    analogWrite(R_VEL_PIN,rv);
  }

  if (rv<0){  // CCW
    digitalWrite(R_DIR_PIN,HIGH);
    analogWrite(R_VEL_PIN,255 + rv);
  }
}

void setMux(int D, int C, int B, int A){ // MSB - LSB
  digitalWrite(MUX_D_PIN , D);
  digitalWrite(MUX_C_PIN , C);
  digitalWrite(MUX_B_PIN , B);
  digitalWrite(MUX_A_PIN , A);
}

void loop() 
{ 
  if (digitalRead(PUSH_PIN)){
    digitalWrite(LED_R_PIN,LOW);
    setMotorVal(50,0);
    setMux(1,0,0,0);
    if (analogRead(MUX_X_PIN) > 512) digitalWrite(LED_B_PIN,HIGH);
    else digitalWrite(LED_B_PIN,LOW);
  }
  else {
    digitalWrite(LED_B_PIN,LOW);
    setMotorVal(0,50);
    setMux(1,0,1,0);
    if (analogRead(MUX_X_PIN) > 512) digitalWrite(LED_R_PIN,HIGH);
    else digitalWrite(LED_R_PIN,LOW);
  }
} 

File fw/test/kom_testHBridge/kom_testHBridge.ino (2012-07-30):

#include <Servo.h> 

int RDirPin = 4;
int RSpeedPin = 3;
int pos = -255;

void setV(int v){
  if (v>255) v = 255;
  if (v<-255) v = -255;

  if (v>0){  // CW
    digitalWrite(RDirPin,LOW);
    analogWrite(RSpeedPin,v);
  }

  if (v<0){  // CCW
    digitalWrite(RDirPin,HIGH);
    analogWrite(RSpeedPin,255+v);
  }
}

void setup(){
  pinMode(RDirPin,OUTPUT); 
  pinMode(RSpeedPin,OUTPUT);  
  Serial.begin(9600);
}

void loop(){
  int value = 255.0*sin(millis()/250.0);
  setV(value);
}

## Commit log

2012-06-18 Starting with the hardware (PCB). The schematic is not finished yet
    [$noname.sch, encoder.sch, interferences.sch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]
2012-06-18 Solved error with kikad library dependency
    [kom.sch]
2012-06-18 Test commit (moved components in schematic)
    [kom.sch]
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2012-06-19 Added IR leds to schematic using an NPN single transistor
    [kom.sch]
2012-06-19 - Changed all the NPN transistors in the schematic for an encapsulated array - Added libraries for RGB and SHARP
    [kom.sch]
2012-06-19 Added fixed sensors
    [kom.sch]
2012-06-20 Added limiting resistors to RGB leds and changed the one for IR
    [kom.sch]
2012-06-20 Almost finished with schematic (needs some extra capacitors)
    [kom.sch]
2012-06-20 Anotated, added some PWRFLAGs, no ERC problems!
    [kom.sch]
2012-06-21 Before branching
    [kom.sch]
2012-06-21 Changed some schematic symbols for the ones found in Monolito. Added bypass capacitors
    [kom.sch]
2012-06-21 New BOM, including the URLs to Farnell components
    [BOM.ods, kom.csv, kom.sch]
2012-06-22 Before merging
    [kom.sch]
2012-06-22 - Using a single barrel connector for power input. - Added Inverse Polarity Protection (IPP) with fuse + crowbar diode. TEST IT!!! - Added On LED
    [kom.sch]
2012-06-22 Small fixes
    [kom.sch]
2012-06-22 Minor changes
    [kom.sch]
2012-06-25 - Changed to JST-XH connector for LiPo - Changed and added bypass capacitors - LC filter on AVCC
    [BOM.ods, kom.sch]
2012-06-25 Before footprint asociation
    [kom.csv, kom.sch]
2012-06-25 - Changed schematic notation - Standard footprints linked
    [kom.sch]
2012-06-25 - Created new modules: Bluetooth LED_IR_Side JST_XH IR_PHT_Side PTH08000 Ultrasonic sensor - Associated components
    [$kom.brd, kom.sch]
2012-06-26 - PCB started: mechanical dimensions drawn - Created a servo outline footprint - Added doc folder
    [kom.brd]
2012-06-26 - Changed 3.3V regulator symbol for a new one in kom lib - Fixed some association problems
    [kom.brd, kom.sch]
2012-06-26 - Placed mechanically fixed components
    [kom.brd]
2012-06-26 - Changed some schematic notation - Started placing modules
    [kom.brd, kom.sch]
2012-06-26 - Placed POWER components
    [kom.brd, kom.csv, kom.sch]
2012-06-26 Added another link to README
    [$kom.brd]
2012-06-27 - Fixed wrong numbering in the phototransistor module
    [kom.brd, kom.sch]
2012-06-27 Changed the encoder IR leds to be 4 in series, so no resistors are needed now
    [kom.brd, kom.csv, kom.sch]
2012-06-27 Changed Schematic and PCB notation
    [kom.brd, kom.csv, kom.sch]
2012-06-27 Placed almost all components. Possible duplicates / wrong caps
    [$kom.brd, kom.brd, kom.sch]
2012-06-27 All the components seems in place
    [kom.brd, kom.csv, kom.sch]
2012-06-27 Fixed some relation errors and changed to circular pads
    [kom.brd, kom.sch]
2012-06-27 Part package revised
    [kom.brd, kom.sch]
2012-06-27 POWER planes drawn (VIn and PGND)
    [kom.brd]
2012-06-27 Power zone routed
    [kom.brd]
2012-06-27 Fixed flipped inCap
    [kom.brd, kom.sch]
2012-06-27 Joined both GND planes
    [kom.brd, kom.sch]
2012-06-27 Reverted to other commit, now the RGB problem is fixed and is half-routed
    [kom.brd, kom.sch]
2012-06-27 RGB routed
    [kom.brd]
2012-06-27 Made the zone bridge wider
    [kom.brd]
2012-06-27 Some routing
    [kom.brd]
2012-06-27 More routing
    [kom.brd]
2012-06-27 Routed Motors from HBridge
    [kom.brd, kom.sch]
2012-06-27 This looks bad... It is getting impossible to route...
    [kom.brd]
2012-06-27 Almost impossible to finish routing. Going to branch and delete some modules :(
    [kom.brd, kom.sch]
2012-06-27 Removed Power Selector and ICSP. 70 pads to route...
    [kom.brd, kom.sch]
2012-07-02 - Discarded the transistor IC, but kept the PWR selector, what implies: - IR Leds are now driven by the MCU, so I've chosen a resistor to consume 40mA - XBee uses a transistor - Using Common Cathode 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
    [kom.sch]
2012-07-02 Deleted all tracks in PCB, starting from scratch. TODO: Change IR order
    [kom.853a.sch, kom.brd, kom.csv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]
2012-07-03 Re-placed all the components in board for easier routing.
    [kom.brd, kom.sch]
2012-07-03 Added fill zones
    [kom.brd]
2012-07-03 Added holes
    [kom.brd]
2012-07-03 - Changed lateral IR LEDs order for better routing - Routed the Motors tracks
    [kom.brd]
2012-07-04 Added HBridge tracks
    [kom.brd]
2012-07-05 With 12 mils bus. I'm going to change to 20 mils
    [kom.brd]
2012-07-05 Ring routed with 20 mils. Some problems arose...
    [kom.brd]
2012-07-05 Routed almost all the ring with 12 mils. In which branch I am?
    [kom.brd]
2012-07-05 Previous 2 commits were corrupted (mea culpa)
    [kom (copy).brd]
2012-07-05 Routed RGB
    [kom.brd]
2012-07-05 Encoders routed
    [kom.brd]
2012-07-05 Routed serial
    [kom.brd]
2012-07-05 Routed all the pads in non-power. Missing some connections to planes
    [kom.brd]
2012-07-05 Only power plane tracks to do!
    [kom.brd]
2012-07-08 Routed all 5V
    [kom.brd]
2012-07-08 - Changed plane clearance - Extended to some islands
    [kom.brd]
2012-07-08 Silkscreen modifications# Please enter the commit message for your changes. Lines starting
    [kom.brd]
2012-07-08 - Improved silkscreen - Packed
    [kom.brd, kom.sch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]
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2012-07-09 - Changed some pads for easier soldering
    [kom.brd]
2012-07-09 Other pads changed
    [kom.brd]
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2012-07-09 The beginning of the end: some silkscreen details modified
    [kom.brd]
2012-07-09 - PCB Finished and sent to fabrication! - Includes fabrication files
    [kom.brd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]
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2012-08-23 Modified schematic for KOMbot 0.2: - Removed power selector - Changed RGB LED resistor values - Removed IR LED resistor - Added 3.3V serial port for Raspberry Pi - Added 5.1V Zener to AN0
    [kom.sch]
2012-08-25 Re-created netlist and associations
    [kom.sch]
2012-08-25 Changed components in pcb, deleted old tracks and power tracks
    [kom.brd]
2012-08-25 Done: MUX module Pinout transistor Remove Power Selector
    [kom.brd]
2012-08-25 Moved servo 5mm up Re-added holes
    [kom.brd]
2012-08-25 Changed some modules' sizes
    [kom.brd]
2012-08-27 - Fixed LED problem - Moved MUX pins so that there is a gap between them
    [kom.brd]
2012-08-27 Finished with hole sizes issues
    [kom.brd]
